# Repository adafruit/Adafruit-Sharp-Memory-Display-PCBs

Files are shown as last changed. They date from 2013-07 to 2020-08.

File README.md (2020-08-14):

# PCB for the Adafruit Sharp Memory display breakout board

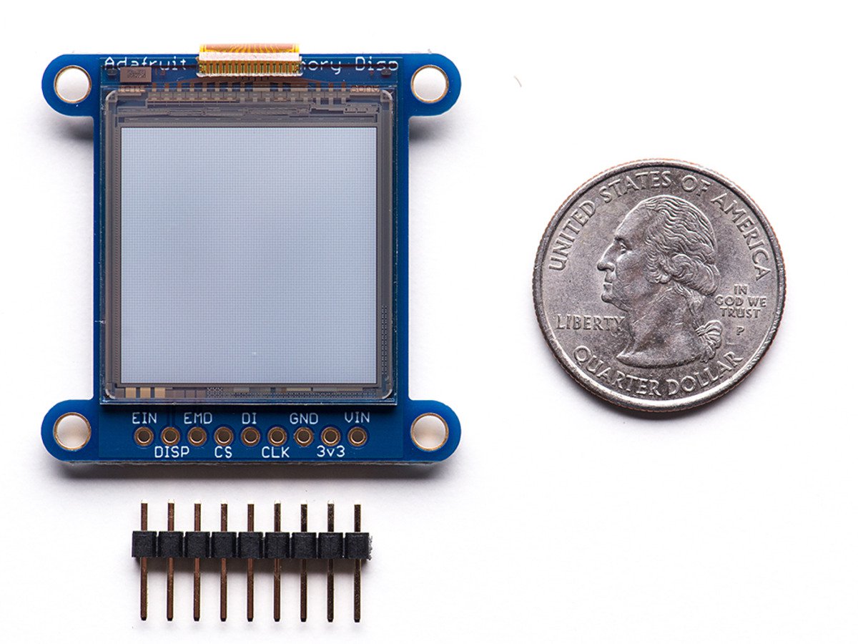
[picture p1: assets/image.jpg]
<br />
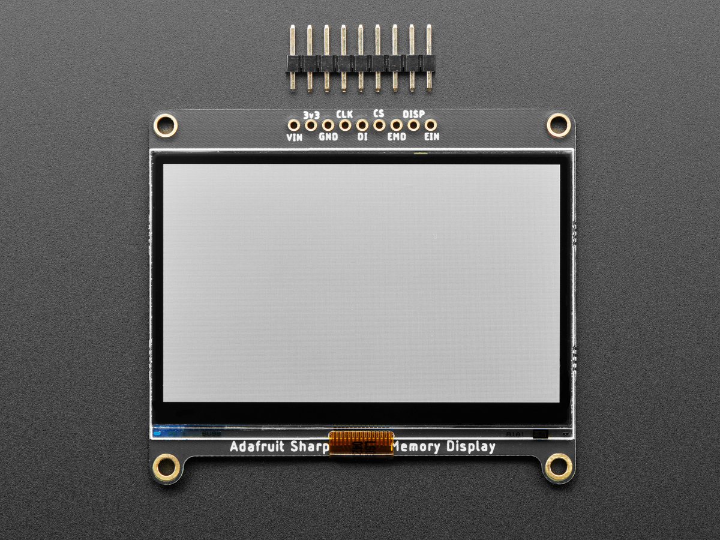
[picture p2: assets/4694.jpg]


[The 96x96 resolution SHARP Memory LCD is no longer made, but we have a higher-resolution 168x144 display available in the shop](https://www.adafruit.com/product/3502).

The 1.3" and 2.7" SHARP Memory LCD displays are a cross between an eInk (e-paper) display and an LCD. They have the ultra-low power usage of eInk and the fast-refresh rates of an LCD. This model has a matt silver background, and pixels show up as little mirrors for a silver-reflective display, a really beautiful and unique look. It does not have a backlight, but it is daylight readable. For dark/night reading you may need to illuminate the LCD area with external LEDs.

The display is 3V powered and 3V logic, so we placed it on a fully assembled & tested breakout board with a 3V regulator and level shifting circuitry. The display slots into a ZIF socket on board and we use a piece of double-sided tape to adhere it onto one side. There are four mounting holes so you can easily attach it to a box.

The display is 'write only' which means that it only needs 3 pins to send data. However, the downside of a write-only display is that the entire 96x96 bits (1,152 bytes) must be buffered by the microcontroller driver. On an Arduino Uno/Leonardo that's half the RAM available and so it might not be possible to run this display with other RAM-heavy libraries like SD interfacing.

Check out [this Learn guide](https://learn.adafruit.com/adafruit-sharp-memory-display-breakout/overview) for details on the boards and usage.

[Then download and install our SHARP Memory Display library](https://github.com/adafruit/Adafruit_SHARP_Memory_Display) and the [Adafruit GFX library](https://github.com/adafruit/Adafruit-GFX-Library). Run the example sharpmemtest sketch with the correct data pins to start drawing lines, circles, rectangles, text, etc!

## License

Adafruit invests time and resources providing this open source design, 
please support Adafruit and open-source hardware by purchasing 
products from Adafruit!

Designed by Adafruit Industries.  
Creative Commons Attribution, Share-Alike license, check license.txt for more information
All text above must be included in any redistribution

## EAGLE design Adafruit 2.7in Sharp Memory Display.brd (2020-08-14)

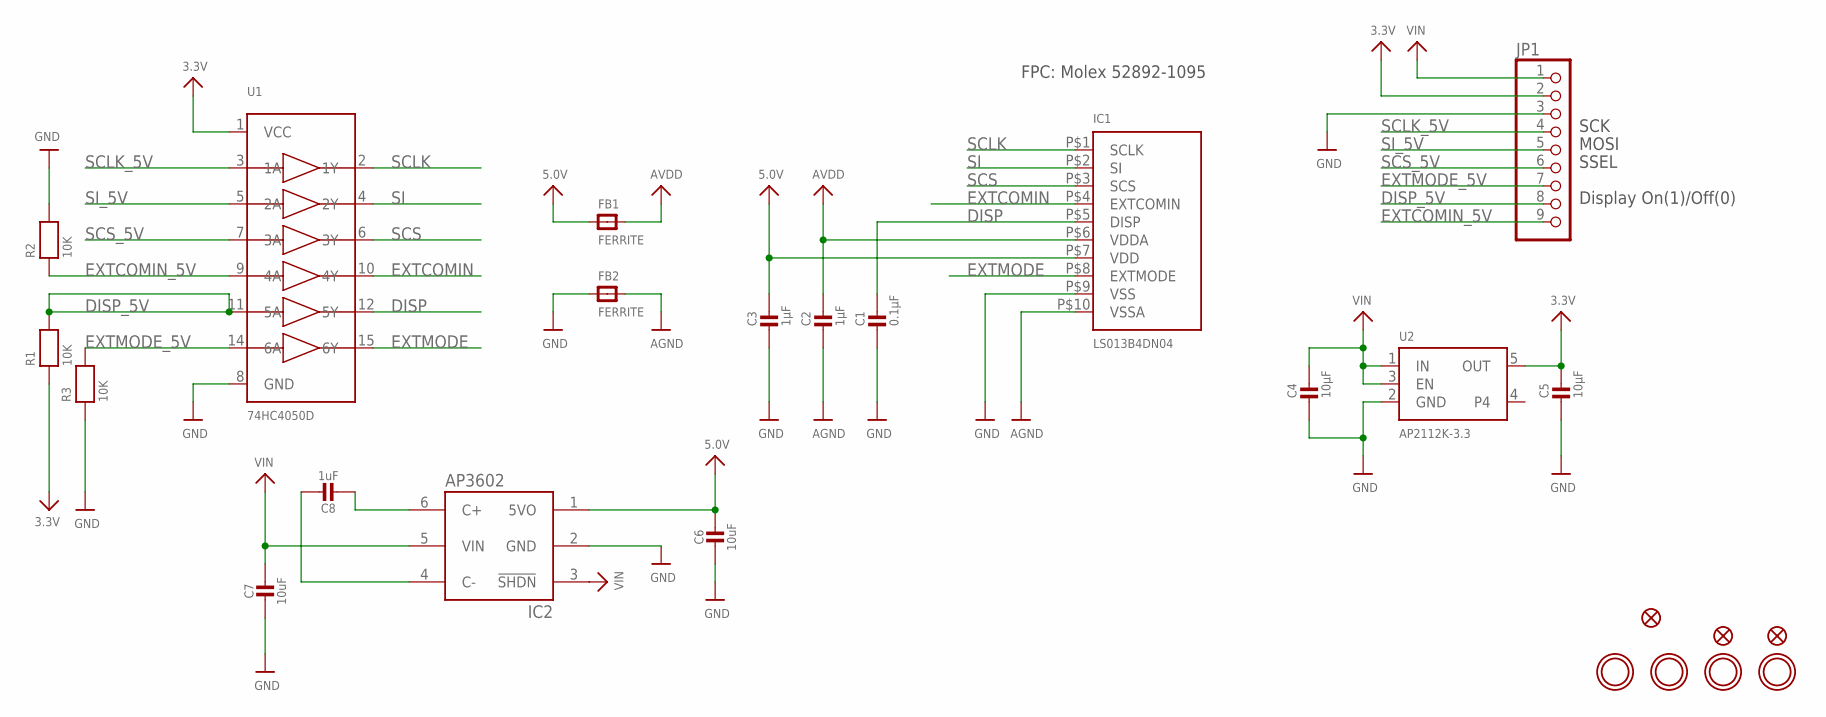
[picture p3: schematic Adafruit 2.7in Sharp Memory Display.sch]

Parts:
C1: 0.1µF; 0603-NO
C2: 1µF; 0805_10MGAP
C3: 1µF; 0805-NO
C4, C5: 10µF; 0805-NO
C6, C7: 10uF; 0805-NO
C8: 1uF; 0805-NO
FB1, FB2: FERRITE; _0805
FID1, FID2, FID3: FIDUCIAL_1MM
IC1: LS013B4DN04; SHARP_2.7IN
IC2: AP3602; SOT23-6
JP1: HEADER-1X970MIL; 1X09_ROUND_70
R1, R2, R3: 10K; 0603-NO
U1: 74HC4050D; SOIC16
U2: AP2112K-3.3; SOT23-5
U$21, U$22: MOUNTINGHOLE2.5_THICK; MOUNTINGHOLE_2.5_PLATED_THICK
U$27, U$28: MOUNTINGHOLE2.5; MOUNTINGHOLE_2.5_PLATED

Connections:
3.3V: C5.1, JP1.2, R1.1, U1.1 (VCC), U2.5 (OUT)
5.0V: C3.1, C6.1, FB1.1, IC1.P$7 (VDD), IC2.1 (5VO)
AGND: C2.2, FB2.2, IC1.P$10 (VSSA)
AVDD: C2.1, FB1.2, IC1.P$6 (VDDA)
DISP: C1.1, IC1.P$5 (DISP), U1.12 (5Y)
DISP_5V: JP1.8, R1.2, U1.11 (5A)
EXTCOMIN: IC1.P$4 (EXTCOMIN), U1.10 (4Y)
EXTCOMIN_5V: JP1.9, R2.1, U1.9 (4A)
EXTMODE: IC1.P$8 (EXTMODE), U1.15 (6Y)
EXTMODE_5V: JP1.7, R3.2, U1.14 (6A)
GND: C1.2, C3.2, C4.2, C5.2, C6.2, C7.2, FB2.1, IC1.P$9 (VSS), IC2.2 (GND), JP1.3, R2.2, R3.1, U1.8 (GND), U2.2 (GND)
unnamed: C8.2, IC2.6 (C+)
unnamed: C8.1, IC2.4 (C-)
SCLK: IC1.P$1 (SCLK), U1.2 (1Y)
SCLK_5V: JP1.4, U1.3 (1A)
SCS: IC1.P$3 (SCS), U1.6 (3Y)
SCS_5V: JP1.6, U1.7 (3A)
SI: IC1.P$2 (SI), U1.4 (2Y)
SI_5V: JP1.5, U1.5 (2A)
VIN: C4.1, C7.1, IC2.3 (!SHDN), IC2.5 (VIN), JP1.1, U2.1 (IN), U2.3 (EN)

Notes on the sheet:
SSEL
MOSI
SCK
Display On(1)/Off(0)
FPC: Molex 52892-1095

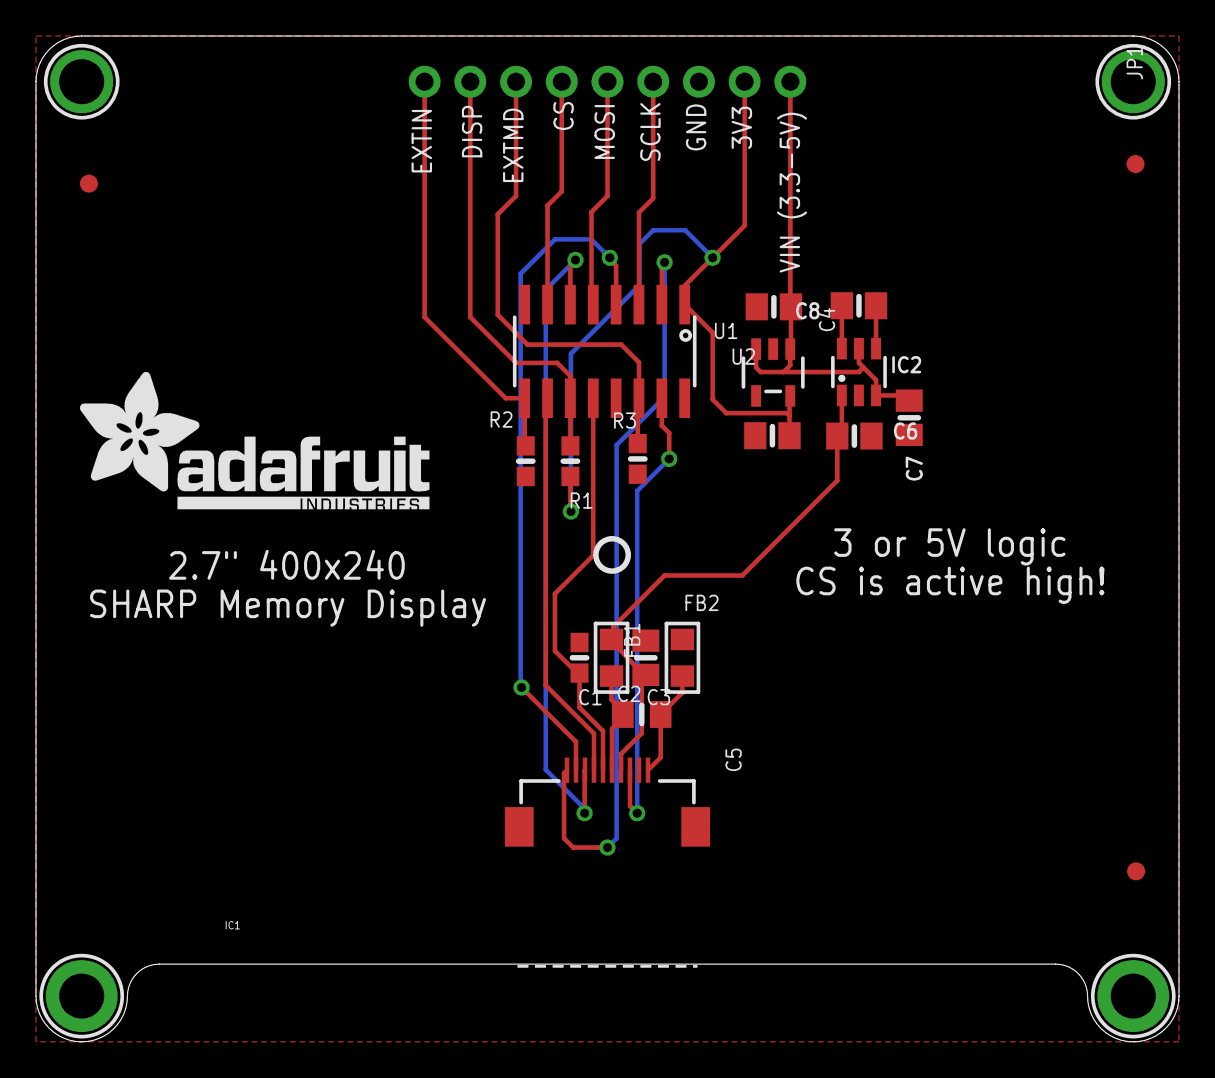
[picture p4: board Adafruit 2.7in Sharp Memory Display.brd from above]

Board: 2 copper layers, 63.5 x 55.9 mm, 27 parts (0 on the bottom side), 20 nets.

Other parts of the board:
U$29: PCBFEAT-REV-040
U$32: ADAFRUIT_TEXT_20MM
